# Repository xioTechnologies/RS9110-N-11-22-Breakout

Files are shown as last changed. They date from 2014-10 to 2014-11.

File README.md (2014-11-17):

RS9110-N-11-22-Breakout
=======================

Breakboard for the Redpine Signals [RS9110-N-11-22](http://www.redpinesignals.com/Modules/Internet_of_Things/Connection_Family/RS-9110-N-11-22.php) Wi-Fi module.  Includes pull-down resistors as per [datasheet](http://www.redpinesignals.com/pdfs/datasheets/RS9110-N-11-22_DataSheet.pdf) (pages 13-16).

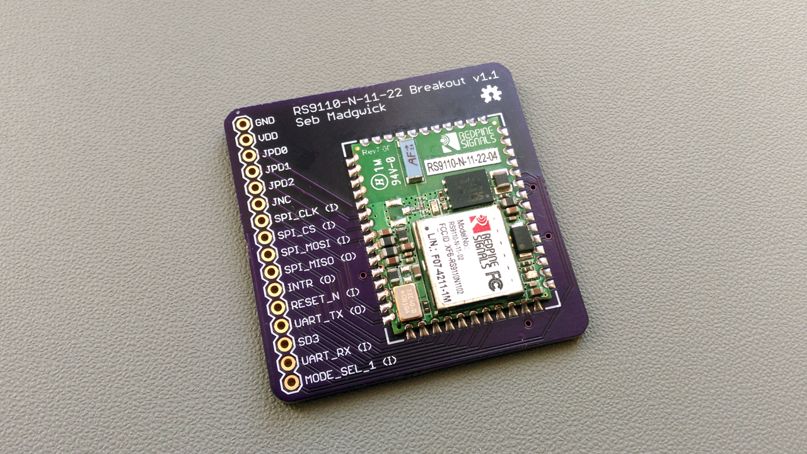
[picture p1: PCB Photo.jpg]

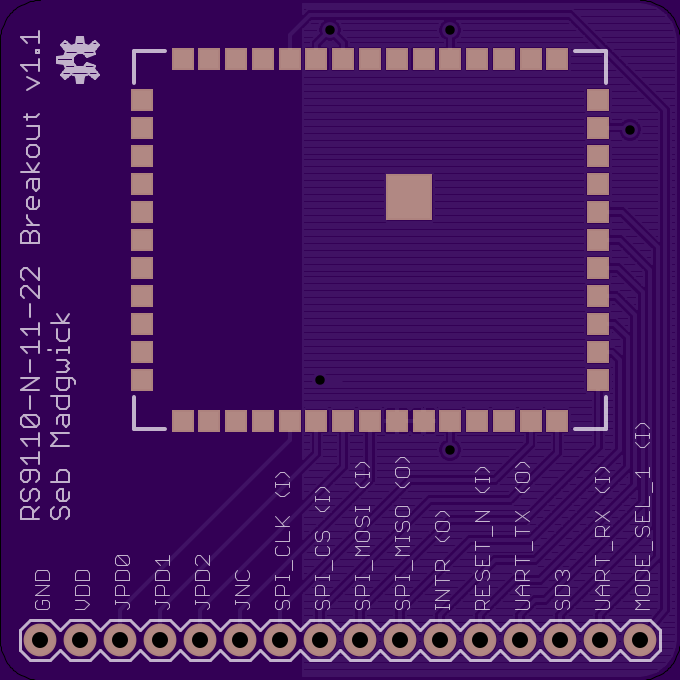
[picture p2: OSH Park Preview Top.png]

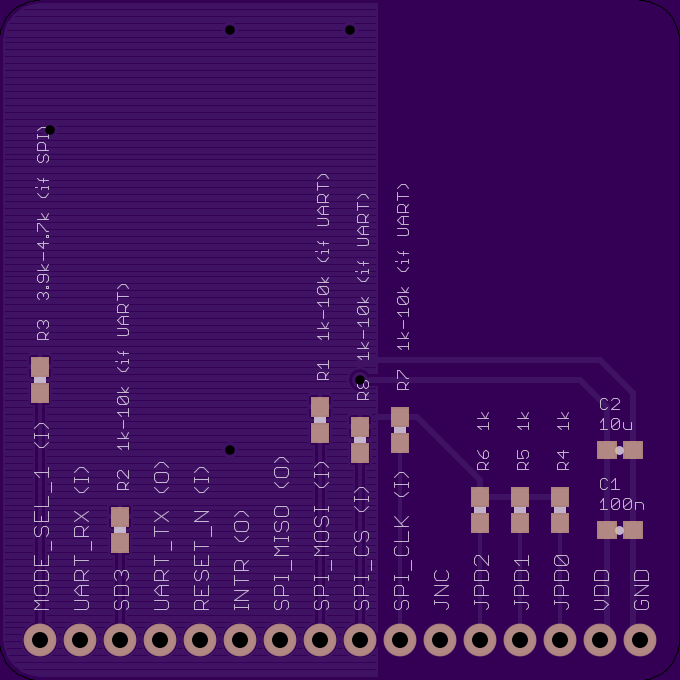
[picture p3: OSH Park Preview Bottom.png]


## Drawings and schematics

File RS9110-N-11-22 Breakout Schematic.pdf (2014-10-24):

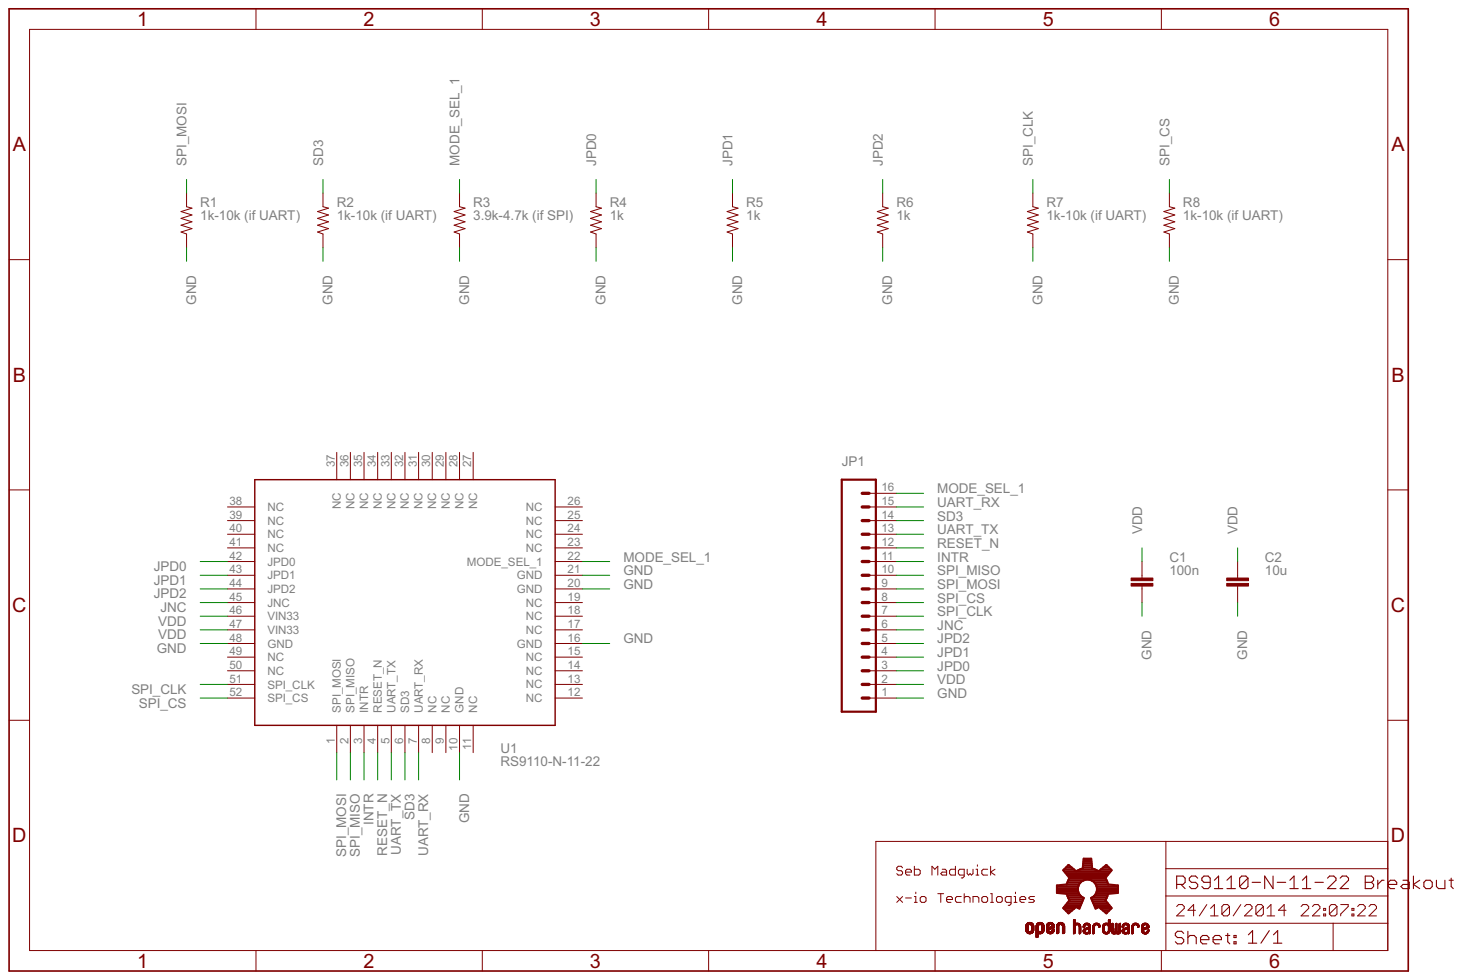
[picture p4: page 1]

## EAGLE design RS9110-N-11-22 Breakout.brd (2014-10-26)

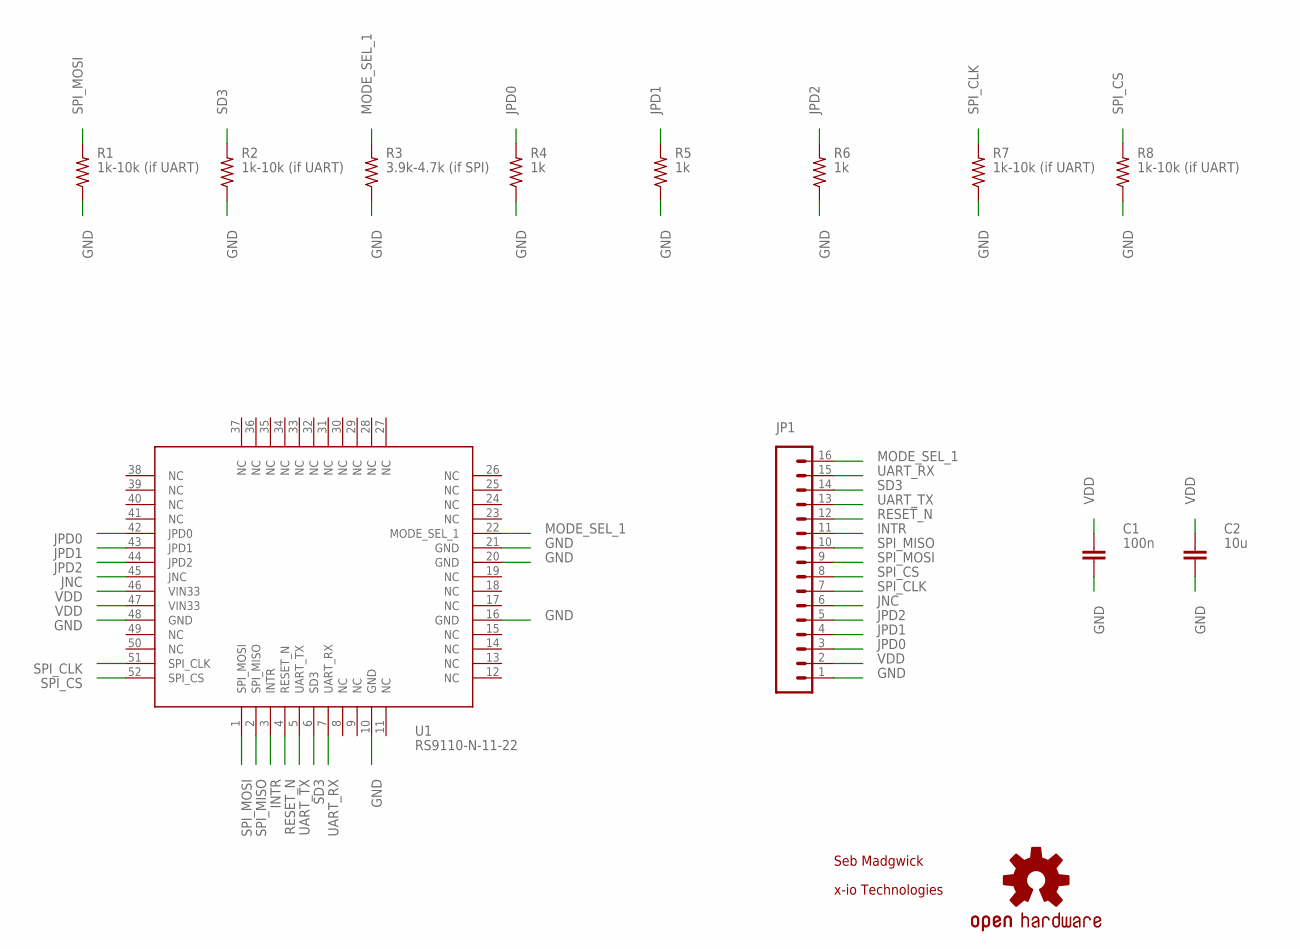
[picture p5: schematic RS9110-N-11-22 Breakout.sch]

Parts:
C1: 100n; 0603-CAP
C2: 10u; 0603-CAP
JP1: M16PTH; 1X16
LOGO1: OSHW-LOGOS; OSHW-LOGO-S
R1, R2, R7, R8: 1k-10k (if UART); 0603-RES
R3: 3.9k-4.7k (if SPI); 0603-RES
R4, R5, R6: 1k; 0603-RES
U1: RS9110-N-11-22

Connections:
GND: C1.2, C2.2, JP1.1, R1.1, R2.1, R3.1, R4.1, R5.1, R6.1, R7.1, R8.1, U1.10 (GND), U1.16 (GND), U1.20 (GND), U1.21 (GND), U1.48 (GND)
INTR: JP1.11, U1.3 (INTR)
JNC: JP1.6, U1.45 (JNC)
JPD0: JP1.3, R4.2, U1.42 (JPD0)
JPD1: JP1.4, R5.2, U1.43 (JPD1)
JPD2: JP1.5, R6.2, U1.44 (JPD2)
MODE_SEL_1: JP1.16, R3.2, U1.22 (MODE_SEL_1)
RESET_N: JP1.12, U1.4 (RESET_N)
SD3: JP1.14, R2.2, U1.6 (SD3)
SPI_CLK: JP1.7, R7.2, U1.51 (SPI_CLK)
SPI_CS: JP1.8, R8.2, U1.52 (SPI_CS)
SPI_MISO: JP1.10, U1.2 (SPI_MISO)
SPI_MOSI: JP1.9, R1.2, U1.1 (SPI_MOSI)
UART_RX: JP1.15, U1.7 (UART_RX)
UART_TX: JP1.13, U1.5 (UART_TX)
VDD: C1.1, C2.1, JP1.2, U1.46 (VIN33), U1.47 (VIN33)

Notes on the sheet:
Seb Madgwick
x-io Technologies

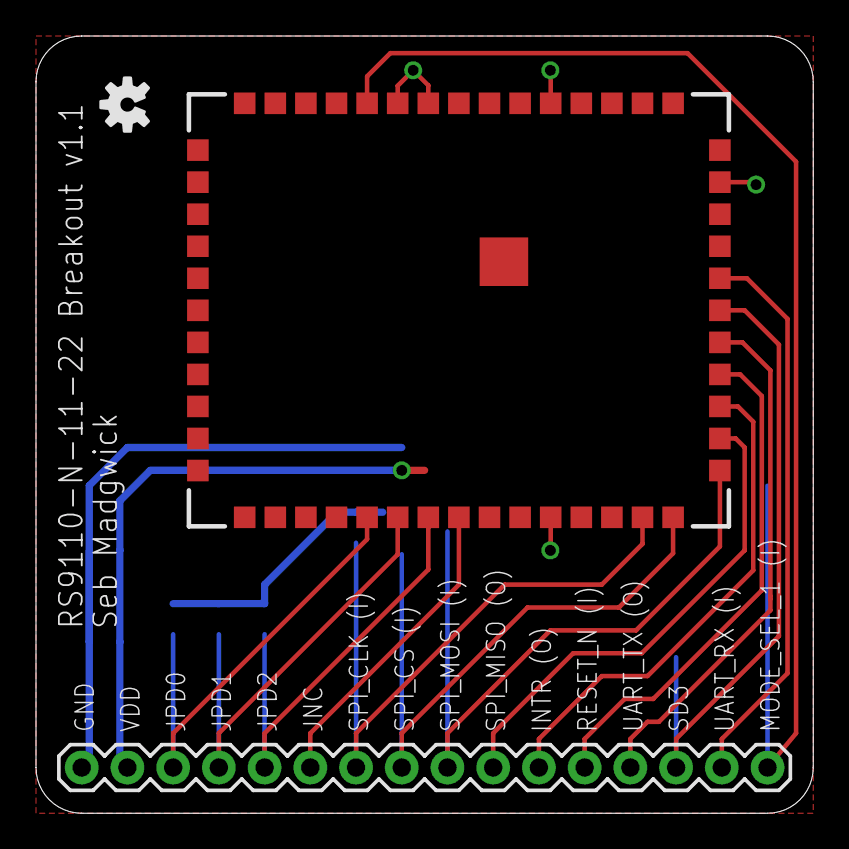
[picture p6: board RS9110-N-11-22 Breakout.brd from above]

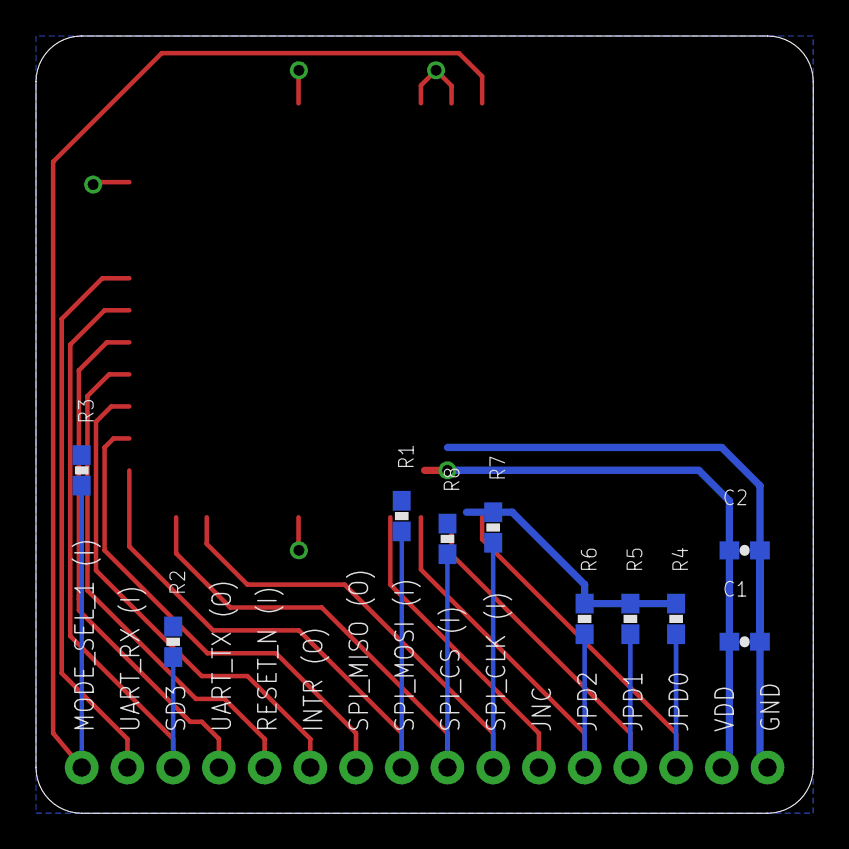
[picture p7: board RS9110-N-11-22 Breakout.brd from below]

Board: 2 copper layers, 43.2 x 43.2 mm, 13 parts (10 on the bottom side), 16 nets.

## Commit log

2014-10-24 Add project files
    [RS9110-N-11-22-Breakout.brd, RS9110-N-11-22-Breakout.sch]
2014-10-24 Correct files names
    [RS9110-N-11-22 Breakout.brd, RS9110-N-11-22 Breakout.sch]
2014-10-24 Add notes about when to populate resistors
    [RS9110-N-11-22 Breakout.brd, RS9110-N-11-22 Breakout.sch]
2014-10-26 Remove copper from around antenna
    [RS9110-N-11-22 Breakout.brd]
2014-11-17 Add PCB photo

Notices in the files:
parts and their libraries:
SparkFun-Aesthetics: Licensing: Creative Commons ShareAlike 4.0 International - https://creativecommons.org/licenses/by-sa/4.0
